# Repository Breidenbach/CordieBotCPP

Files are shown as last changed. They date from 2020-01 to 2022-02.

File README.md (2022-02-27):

# Cordiebot2
This bot was created from a brass lamp found in a resale store. CordieBot 2 is a remake of the original Arduino version which was made as a present for my granddaughter's 11th birthday.

Here is a video of the CordieBot in action...  

https://user-images.githubusercontent.com/1779744/133836883-783d6fb2-bbbe-4077-a870-86ad14fcd4a6.mp4

The original Arduino version can be found in the repository: https://github.com/Breidenbach/CordieBot .

Note that the CordieBot is a bot named after my granddaughter Cordie (duh).

The new and improved CordieBot uses a Raspberry Pi model 3 A+ with logic written in C++.

- Another version is here on github in Python, but had many mysterious memory leaks and could only run a few hours before it used up all system memory resources.  Clearly that was unacceptable, so this version was created in the hopes that I could control memory leaks better in C++ than in Python.

This version uses logic similar to the original for the light show, but now has new features:
- Uses the Cepstral voice for better speach.
- Senses the number of times the touch switch is pressed in a short time:
  -  1 touch and CordieBot says the time of day and date, possibly followed by a proclamation.
  -  2 touches and she says the current weather based on the location of the CordieBot, possibly followed by a proclamation.
  -  3 touches and she says the quote for the day from BrainyQuote.com.
  -  4 touches to repeat the previous proclamation.
  -  5 touches and she tells her version.
  -  8 touches and she tells her origin story.
  -  9 touches and she tells her internal temperature.
- Holding the button for more than 5 seconds causes a shutdown of the system, so that a reboot can occur.  CordieBot must be powered off and powered back on to reboot.
- Checks for a USB drive on start up, and when internet access is disrupted.  If the USB drive is found, checks for a new wpa_supplicant.conf file or cordiebot executable files.  If either is found, copy the file(s) using special scripts into the appropriate directory. (the executable files are only copied if the date on the files is newer than the dates on the CordieBot) Thus this version has the capability of changing the WIFI name and password without a keyboard as well as updating the software.  The USB drive is unmounted after files are copied, as it is expected that the USB drive will be removed after this process.
- This version uses multithreading to overlap the light show and speech.
- The CordieBot has an internal fan and temperature sensor, so that when the internal temperature is high the fan may help cool its logic.

## PROCLAMATIONS

After the weather and time messages, the CordieBot will randomly make a proclamation drawn from a file of messages.  There are three types of proclamations:  for a specific date, for a specific month and day of any year, and for any date.  Proclamation examples:  "Today is mom's birthday" and "I am not the droid you are looking for".  The random selection is prioritized to most often select the current day's statements, followed by those that are for any year on the current date, followed by any other statements.

The proclamation file can be updated remotely using PubNub as a secure communication channel to the CordieBot and cbot_communication on a host computer.  Messages may be added, updated, deleted, and retrieved.  Using the cordieBot_listen program on a local RaspberryPi, the messages can be checked for how they will sound when they are spoken.  Sometimes phonetic editing is required to make a message sound good.  The message text may be altered using the Speech Synthesis Markup Language (https://www.w3.org/TR/speech-synthesis11/) and then tested using a local RaspberryPi.

## DEPENDENCIES

wiringPi is used to access the Pi hardware inputs and outputs.  aoss is used to speak the phrases.

## FILES

### Library modules:
- cbotLights (.cpp and .h) provides the ramping and color change routines for the tri-color LEDs.
- cbotButton (.cpp and .h) debounces and counts presses of the touch switch.
- GPIOtoWiringpi.h maps RaspberryPi GPIO numbers to Wiring Pi numbers.
- messages (.cpp and .h) handles many functions relating to loading, updating, and storing the proclamation file.
- wiringPiMCP3002 (.cpp and .h) connects to the MCP3002 chip over SPI to read temperature values from the TMP36 sensor.
- wiringPiTLC59711 (.cpp and .h) sends data to the adafruit TLC59711 LED PWM board.

### The CordieBot application:
  - cordiebot: the main script
  - CordieBot update scripts, executed when a USB drive is sensed:
    - cordiebot_ctl.sh: copies cordiebot files from a USB drive to the current directory if the files on the USB are newer, always copiies the wpa_supplicant.conf file to /etc/wpa_supplicant
  - cordiebot_listen:  uses PubNub to communicate with the html app on home computer 
  - cordiebot_speak:  auxiliary program to receive the message from the html file and speak it.  This provides the abiity to listen to the messages prior to updating the proclamation file.  
### Scripts to remotely update the proclamation file:
  - cbot_communication.html:  communicates from a host computer to the CordieBot to maintain the file of proclamations spoken after the time is spoken.
  - Cbot_style.css:  style definitions used by cbot_communication.html
### Support files:
  - createproclamationfile.py:  Used to create an initial list of statements for the CordieBot to recite.
  - keys.js:  container for the CordieBot PubNub keyes used for communication to the CordieBot.  This file is used in all the files used in the PubNub communications - the host computer HTML file and CordieBot's listen program.
  - cordiebot_ctl.service.txt, cordiebot.service.txt, and cordiebot_listen.service.txt: These files, with the .txt extension removed, should be place in the /etc/systemd/system/ directory to start the CordieBot applications when the system is booted.

## DIRECTORY STRUCTURE

Make files and execution defaults are dependent on the file structure below.  Note that after building the application files, the executables must be moved to /home/[user]/CordiBot2 to be used automatically on boot.

/home/[user]/CordieBot2/ (Executables and scripts for running CordieBot)

/home/[user]/CordieBot2logs/  (Directory for logs when auto running at boot.  This directory must have write permissions for all.)

/home/[user]/ccpCordie/ (files for building CordieBot)
  - cbot/ (cordiebot main source files)
  - lib/ (specific libraries created for cordiebot features)
  - c-core/ (PubNub files)

## BOOT STARTUP

To start CordieBot on reboot, move the cordiebot_ctl.service.txt, cordiebot.service.txt, and cordiebot_listen.service.txt files to /etc/systemd/system/ with the .txt extension removed.  Then execute the following commands:

  - sudo systemctl disable cordiebot_ctl
  - sudo systemctl disable cordiebot
  - sudo systemctl disable cordiebot_listen
  - sudo systemctl daemon-reload
  - sudo systemctl enable cordiebot_ctl
  - sudo systemctl enable cordiebot
  - sudo systemctl enable cordiebot_listen

## PRINTED CIRCUIT BOARD

To simplify connecting to external devices and provide some interface logic, a small PCB as been developed in the format similar to the RaspberryPi HAT.  The major diference is that this board does not have the ROM to identify it to the RaspberryPi.  The board was developed using KiCad, and files for the board are included in this repository in the PCB directory.

## HARDWARE

As mentioned above, the computer for the CordieBot is a RaspberryPi model 3A+.  Additional logic includes:
-  TMP36GT9Z temperature sensor
-  MCP3002 analog to digital converter (for reading the temperature sensor)
-  PAM8302A audio amplifier
-  AT42QT1010 adafruit momentary touch sensor
-  TLC59711 adafruit 12 channel 16 bit PWM LED driver
-  Sunon GM0501PFB3-8 fan
-  HEP170 diode and 2N2222 transistor for the fan driver
-  Miscellaneos resistors, capacitors, wiring.

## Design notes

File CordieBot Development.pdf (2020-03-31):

# CordieBot Design and Software

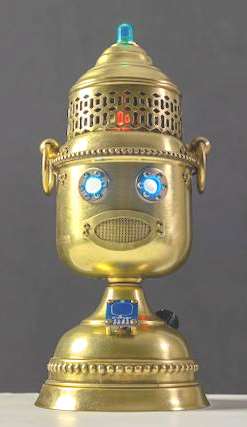
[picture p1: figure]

## A creation by Hal Breidenbach

2020

Photo: Jennifer Patselas

2

### Table of Contents

3

### Background

This project was one of the most complex that I have worked on as an individual. The initial concept was simple, and contained in the first version. Using a repurposed lamp as a body, make a talking head which would tell time, make some inane comments in a somewhat mechanical voice, and display a light show.

The first version, simply named CordieBot, was based on an Arduino computer. It did the light show, had a number of comments to recite, and some time after
my granddaughter Cordie received it she delegated it to back of a
bookshelf.

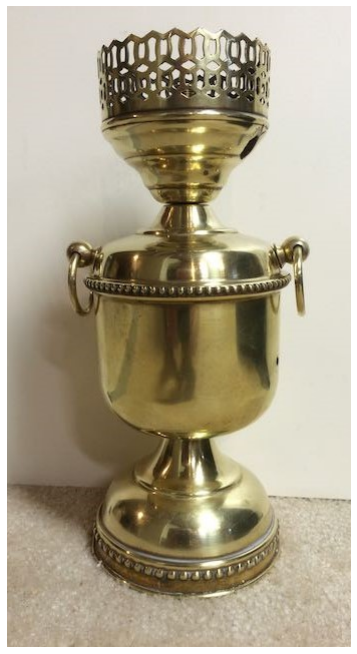
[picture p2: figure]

Clearly, a more interesting bot was needed. But the capacity of the Arduino had been exhausted. Enter the RaspberryPi 3 A+. This computer could fit inside the lamp body, and had plenty of horsepower to do more processing. In addition, it has built in WiFi.

The CordieBot now can give the time of day along with informative or inane comments in a reasonably natural sounding voice, give the temperature and weather outside, recite a quote for the day, and when it gets warm inside its body it can turn on a cooling fan. It has a comparable light show to its predecessor, it can be updated using a USB drive, and the messages it recites can be updated over the web using secure communications.

Additionally, since the messages will be spoken, I wrote a script to run on the RaspberryPi to simply state the message so I can listen
to it before I insert it into the file of messages that are played after
the time is spoken.

The new capabilities were initially all programmed using Python, but when checking memory usage, it was clear that there was a memory leak, and a significant one. The memory on the RaspberryPi was totally filled in less than 24 hours. I was using a number of packages downloaded from free sites, and I could not locate the leak. After some effort at fixing the problem, I decided that the easier path would be to rewrite the code in c++.

Overall, the current CordieBot is 3-1/2 years in the making, although there have been long gaps in the development process. It contains about 3700 lines of original code in addition to the downloaded libraries.

Figure 1 The Lamp

4

### CordieBot components

Hardware—a repurposed lamp, RaspberryPi, lights and sound.
CordieBot software—resident on the CordieBot, written in c++.
CordieBot message management software—resident on the CordieBot, written in c++. CordieBot update scripts—resident on the CordieBot, written in shell script.
Message web page—running on a host computer, written with JavaScript with a CSS file. Message test software—running on a RaspberryPi so messages can be heard before being sent to the CordieBot. Written in c++.

### The learning curve

The CordieBot software challenged me to learn new applications, tools, and techniques:
1. Getting PubNub (the communications software) to work on the RaspberryPi.
2. Writing a web page to communicate with the CordieBot 2.
3. Using json to format and decode the messages.
4. Interfacing an Analog to Digital translation chip to the RaspberryPi and generally using the R-Pi hardware I/O.

### 5. Programming the speech functions and multi threading the software to overlap the light

show and speech.
6. Updating the WiFi access from a USB drive.
7. Updating its own programs from a USB drive.
8. Using a single button to control the program functions.

### Speech

For the natural sounding speech that CordieBot 2 has I purchased the Callie voice from Cepstral (cepstral.com). The speech is actually delivered through a program called Swift, and is accessed using aoss on the R-Pi. I slowed the speech down about 1/3 to make it clearer and easier to understand. It is possible to insert pauses, stress and pitch changes, and phonetic strings into the speech commands. I found the pauses useful, the others not as much.

### Light show

While the speech capability is a major feature of the CordieBot, the light show adds drama. As a talking head, it is important to know when it is awake. When requested to speak, the Cordie-Bot LED eyes are ramped up in a soft blue. Then an LED in the interior (brain) and on the top (head) are ramped through a series of random colors. When the speech is done, the eyes are ramped down to dark. A class is defined to handle the light show and ramping the eyes.

5

### Controlling the CordieBot—the touch button

On the front of the CordieBot is a blue touch sensitive button which selects the function. Based on the selection, the CordieBot speaks a desired response. The selection is based on the number of touches in a short period of time.
1 Speak the time, with a possible message.
2 Announce the local weather and temperature.
3 Read the “Quote of the Day” off the Quote of the Day website. 4 Repeat the last message spoken.
5 Say its version number.
6 Check for updates.

### 8 Recite the origin story of the CordieBot

9 Say its internal temperature.

### 17 Say “You found an Easter egg, good job”. This last command is not publicly

documented, I am curious if it will be found.

The button has its own class to read the button and determine the number of touches. There is an allowable interval separating the touches, and when no touches have been sensed for a longer period of time the number of touches that has been sensed is returned to the calling routine.

### CordieBot Communications

The CordieBot communicates with a server computer to update a message file. The components of the communication capability include and html script running in a browser on the server, a program on the Raspberry Pi, and a communication link.

### Messages

The message feature of the CordieBot was the driver behind much of its other capabilities. The messages are kept in a file (proclamations.txt) on the CordieBot in json format. Three c++ classes, Message, MsgList, and MessageBank, provide the ability to update and access the messages from a resident vector. At start-up the messages are read into the vector, and the messages are re-read whenever the file is updated. The message management software receives updates from the host computer and updates the file as needed. The message management software, accessed from another computer, has the capability to:
Add messages
Change messages
Delete messages
Retrieve a message (back to the web process) Retrieve all messages
Resequence the messages

The messages are formatted to contain the following:

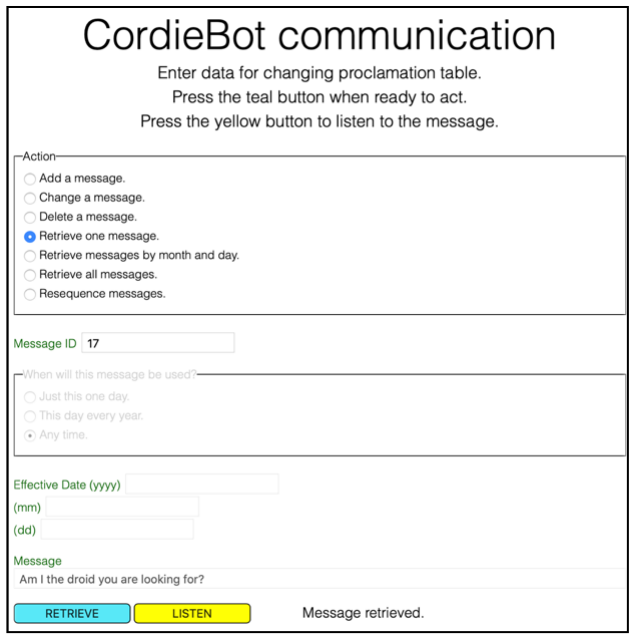
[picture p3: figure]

6

ID – a unique identification number Year, Month, and Day
Type
Content – what will actually be spoken

The message type describes how the message will be used.
Type 1 – the message has a year, month, and day on which it will be used (this can be used to announce a special event that only occurs once).
Type 2 – the message has a month and day and may be used on that day any year (this can be used for announcing a birthday or anniversary).
Type 3 – contains no date values, and may be used any time.

The messages are used randomly, and many times the time will be spoken with no message at all. The software is structured to prefer the type 1 message if one is present for that date, then a type 2 message if one is present for that day of the year, and if neither of the above a type 3 message.

### PubNub

PubNub is a system of software that can be used for a chat application (plus many other uses). For individual non-commercial use it is free. It uses keys that are many characters long so it is very secure. And it has sample
software for web pages and for
C++. The communication from
the host computer is published on a channel (in CordieBot’s case, from an html web page) and received by the CordieBot which subscribes to that channel. Both the channel name and the keys must match. The CordieBot can then publish a response on that channel, and the web page, subscribing to that channel, can receive the response and display it. The PubNub keys are kept in a separate file, keys.js, which can be used by any of the programs that contain PubNub functions: the update program on the CordieBot, the html script on the host computer, and the speak program on another R-Pi.
Figure 2 Screen shot of the message management page.

7

### The host computer web page

On the host computer I wanted an application that would let me do any maintenance on the list of messages located on the CordieBot. This, with PubNub, lets me add, change, delete, and display messages remotely, with a secure connection (the PubNub keys contain 32 unique characters). With this connection, I can add from home new messages for my granddaughter to hear the next time she checks the time. I can have a local R-Pi set up to listen to the messages before they are sent. The web page (figure 2) is written in JavaScript and uses a CSS file that my daughter created.

### “Headless” updates to the CordieBot software

The CordieBot application can be commanded to check for a USB memory stick, and if present will check for a wpa_conf file to add or change a WiFi connection, as well as checking for updated application software. If the software is being update, the application will move the new version to the appropriate directory and then reboot.

### Construction

When I found this brass lamp in the Habitat Restore, I had just a glimmer of what it would become. The rings on the sides do look a bit like earrings, and the body something like a face, so I decided to take that idea wherever it would lead me.

The following description of how the CordieBot was constructed is not intended to be a how-to. It is unlikely that you will find a lamp exactly like the one I found. But perhaps you can get some ideas of what you can do from the way I constructed the CordieBot.

The separate parts of the lamp are held together by two 3/8” hollow threaded rods that are common to most lamps. When the parts are re-ordered, the same rod may be used to hold the new arrangement together. Since it is hollow, the wiring can be run from one segment to the next.

Note that the very top of the lamp is inverted, making a space at the top that is open. Inside this open space is an LED which I refer to as the brain lamp. At the top of the hollow tube that holds the upper part to the main part of the head is another
10mm LED which fits nicely the end of that tube. I refer to
it as the head lamp.

The eyes are attached to a piece of perf board set behind the eyeholes, which are bordered by brass washer held to the face by 6 2-28x1/8” bolts giving a steampunk look to the construction.
The lips are a cutout piece of sheet brass over brass screen
obscuring a hole to the interior. The speaker is behind the
hole, and the lips are held to the face by 4 of the 2-56 x

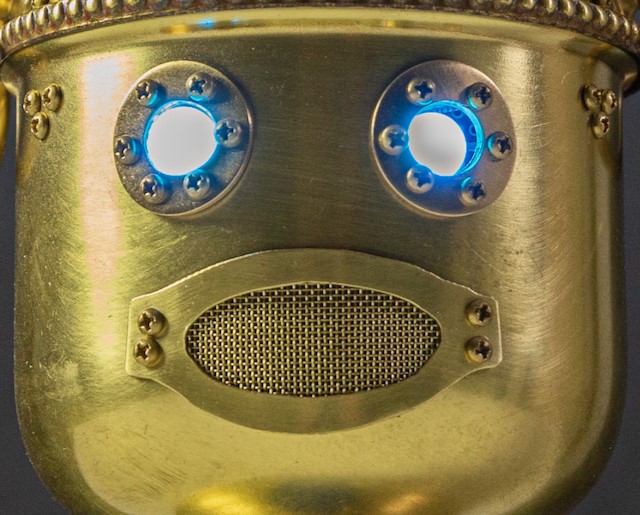
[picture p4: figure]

1/8” bolts. An interior bracket holds the speaker in place, Figure 3 Face detail.

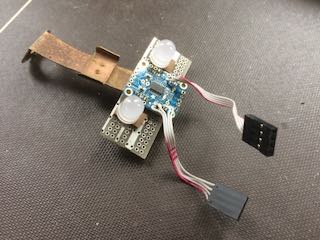
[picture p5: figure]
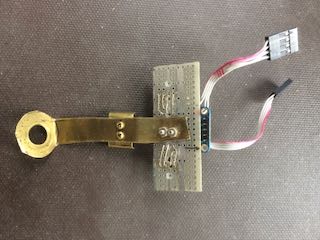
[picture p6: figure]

8

and supports a small piece of perf board which holds the eyes and the LED PWM board.

### Interior Bracket

The interior bracket is the only hardware construction inside the CordieBot. It is sized to fit the space in the lamp. The bottom of the bracket has a 3/8” hole and fits over the rod connecting the base to the head. This allows the bracket to be held by the same nut that keeps the head attached to the base. The bracket has a U shaped holder to keep the speaker from sliding. The bracket is bent so that the eyes are held in place behind the eyeholes, and there is tension on the speaker to hold it in place. A small piece of foam on the back of the speaker helps keep it steady without affecting the sound. (Figures 4 and 5)

The wires from the eye LEDs on the perf board are woven through holes in the board and back up to the LED PWM board. A small piece of 1/8” Masonite spaces pushes the eyes out a bit to let them project through the eyeholes better. The head and brain lamps connect to connectors wired to the LED PWM board. (Figure 6)

Figure 4 Lamp and speaker assembly showing eyes and PWM driver board. The flanges at the midpoint hold the speaker in place.

Figure 5 Rear side of the lamp and speaker assembly. Note that the perf board is connected to the bracket by two 2-56 bolts.

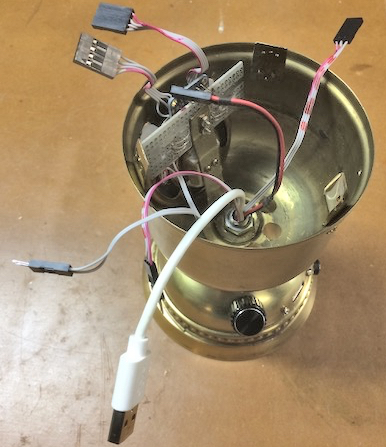
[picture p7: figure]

Figure 6 Interior of the “head” showing the installed eye bracket and wires from the base.

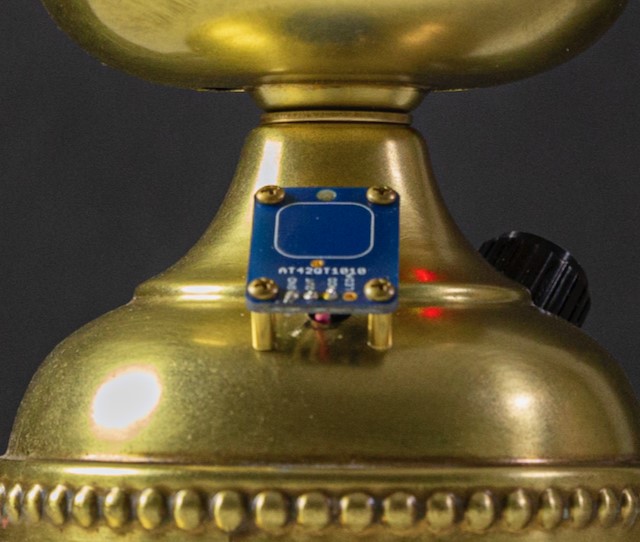
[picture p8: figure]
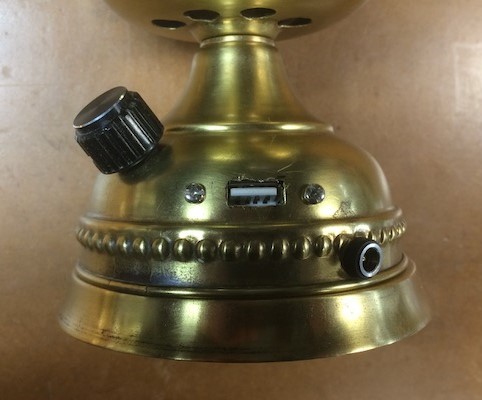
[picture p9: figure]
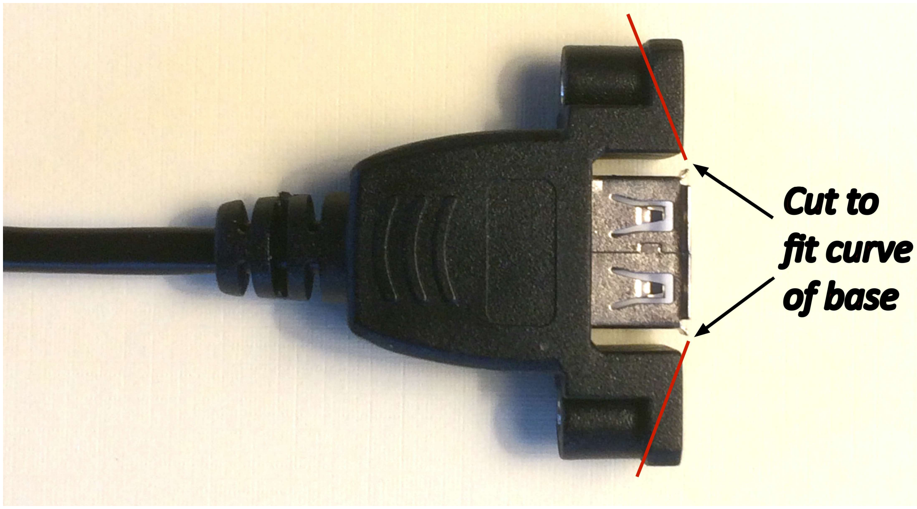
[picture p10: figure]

9

### The Base

The base of the CordieBot holds the input button, the volume control, power input, and a USB connector that directly connects to the R-Pi.

The volume, power, and USB are on the back, while the input button is on the front. The button is held in place by four 2-56 x 1/2” bolts and is held away from the base by 1/4” pieces of 1/6” brass tubing.

To make the USB cable fit into the circular form of the base, I cut the corners off of the cable. (Figure 10)

The wires will be fed up through the 3/8” threaded tube that holds the base to the head. After the wires are fed

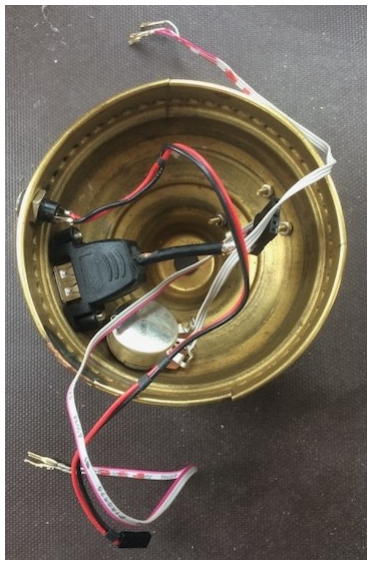
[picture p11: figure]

through the tube they may be inserted into their connectors.

Figure 7 Rear of the base, showing the volume control, USB port, and power connector.

Figure 8 Front of the base, showing the touch button.

Figure 9 Inside the base.

Figure 10 Cuts to end of USB cable.

10

### The Upper Head

Two parts from the original lamp make up the upper head. The very top part is inverted from the original lamp. With its open cutout design it seemed just the place to put a brain light. The two pieces are held together with a length of the standard 3/8” threaded rod. The very top light, or head light, is glued to the end of the threaded rod. The wires for this light are soldered to the LED leads and insulated with pieces of heat shrink tubing. The head lamp and brain lamp are programmed to do a light show any the CordieBot speaks.

In addition, there is a miniature fan which is operated when the temperature gets too high in the CordieBot to cool the interior. The fan moves air from the interior through a hole in the bottom of the two pieces and is hidden by the grated portion of the top of the two. It is held in place by four 2-56 x 1/2” bolts. The brain lamp is glued into a 3/8” hole which is also inside the perimeter of the grated portion of the top. Figure 12 shows the locations of these components, as well as the wires going to the head lamp through the hollow

threaded rod. Note that there are ventilation holes in the body of the head, which can be seen in figure 7.

Since the Raspberry Pi will be inside the head, the typical threaded rod structure of a lamp cannot be used to hold the parts together. Figure 13 shows the location of the bracket, which is held by six 2-56 x 1/8” screws. The bracket holes for the screws are tapped so no nuts are required. Six screws are hardly necessary, but adds to the steam punky look of the CordieBot. There are three brackets, one at each side just in front of the loops, and
one in the middle in the back. The brackets may also be
seen in Figure 12 (the back side is at the top left of the picture).

Figure 11 Upper head detail

Figure 12 Interior of the top pieces.

Figure 13 Bracket to hold the top on.

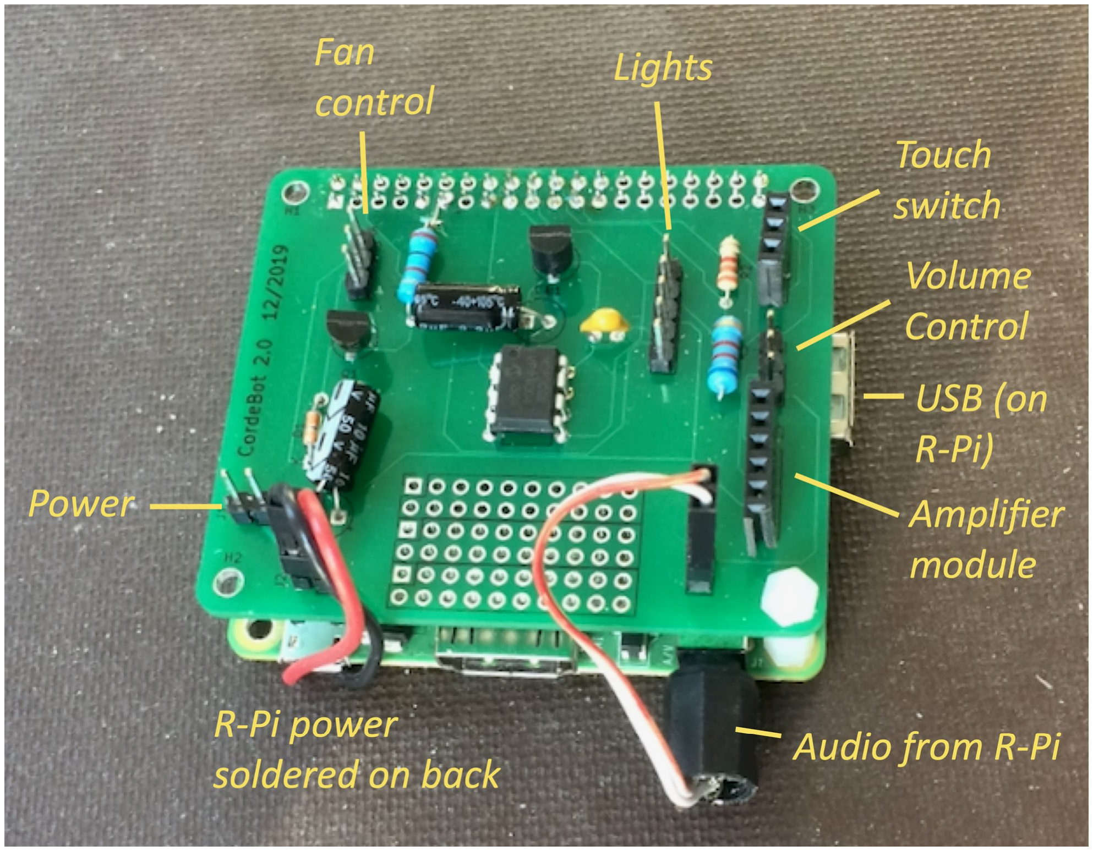
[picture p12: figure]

11

### Electronics and the Raspberry Pi

The electronics interfacing the Raspberry Pi with the daughter boards and other components are on a custom PC board. It is similar to the Raspberry Pi HAT, but lacks the ROM to tell the R-Pi what the board is. Since this is a unique and dedicated application, I didn’t feel it was necessary to have the ROM ID. I also didn’t feel a need to go through the learning curve of including it in the design and altering the software to look for the ID. The populated interface board is shown in Figure 14.

Note that the power to the whole system attaches to this board, and that a connector from this board supplies power to the R-Pi. While there are 5 volt power lines on the 40 pin connector, these are not protected and it is better to supply power to the R-Pi as if it were connected to the power input jack.

A complete set of schematics and a design of the PCB board is available in another document.

The Raspberry Pi is simply inserted into the head of the CordieBot. I originally planned to connect it with bolts to the back of the head, bur realized that it wasn’t necessary. I did cover anything conductive on the edges of the Raspberry Pi with electrical tape to insure nothing could get shorted out if it did get close to the brass case.

All of my wiring is color coded with the wire for pin 1 marked in red.

Figure 14 Raspberry Pi 3A+ and “HAT”

Figure 15 Raspberry Pi
inside the head.

Figure 16 Under construction. Yes, the rats nest of wiring did get confusing
from time to time, but it
all worked out in the end.

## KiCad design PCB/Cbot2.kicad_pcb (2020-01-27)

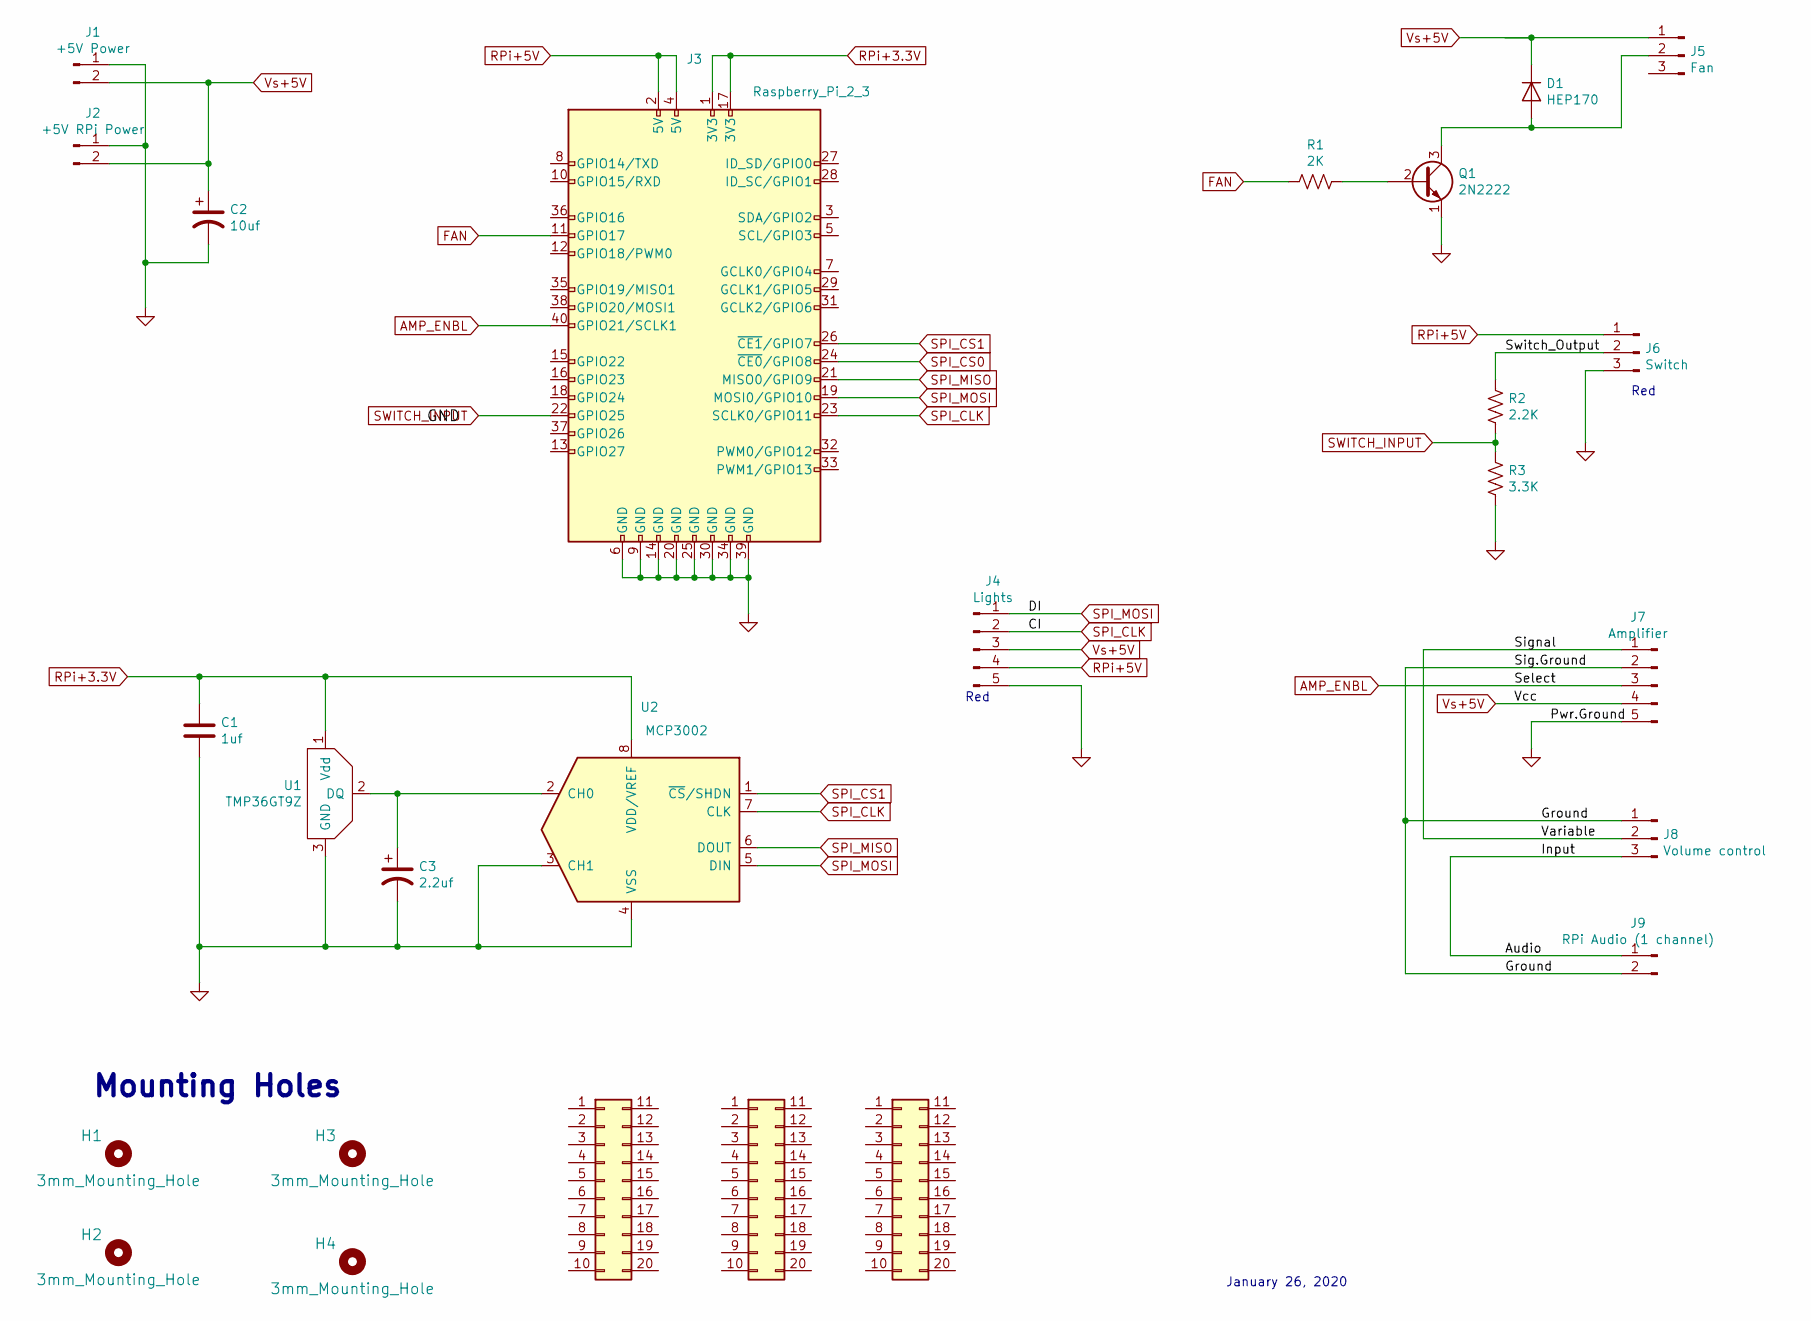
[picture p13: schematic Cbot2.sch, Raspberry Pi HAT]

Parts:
C1: 1uf; C_Disc_D3.0mm_W1.6mm_P2.50mm
C2: 10uf; CP_Radial_Tantal_D5.0mm_P2.50mm
C3: 2.2uf; CP_Radial_Tantal_D5.5mm_P2.50mm
D1: HEP170; D_DO-35_SOD27_P7.62mm_Horizontal
H1, H2, H3, H4: 3mm_Mounting_Hole; NPTH_3mm_ID
J1: +5V Power; PinSocket_1x02_P2.54mm_Vertical
J2: +5V RPi Power; PinSocket_1x02_P2.54mm_Vertical
J3: Raspberry_Pi_2_3; PinSocket_2x20_P2.54mm_Vertical
J4: Lights; PinSocket_1x05_P2.54mm_Vertical
J5: Fan; PinSocket_1x03_P2.54mm_Vertical
J6: Switch; PinSocket_1x03_P2.54mm_Vertical
J7: Amplifier; PinSocket_1x05_P2.54mm_Vertical
J8: Volume control; PinSocket_1x03_P2.54mm_Vertical
J9: RPi Audio (1 channel); PinSocket_1x02_P2.54mm_Vertical
J10, J11, J12: Pads; PinSocket_2x10_P2.54mm_Vertical
Q1: 2N2222; TO-92_HandSolder
R1: 2K; R_Axial_DIN0204_L3.6mm_D1.6mm_P7.62mm_Horizontal
R2: 2.2K; R_Axial_DIN0204_L3.6mm_D1.6mm_P7.62mm_Horizontal
R3: 3.3K; R_Axial_DIN0204_L3.6mm_D1.6mm_P7.62mm_Horizontal
U1: TMP36GT9Z; TO-92L_HandSolder
U2: MCP3002; DIP-8_W7.62mm

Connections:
/Audio: J8.3, J9.1
/Ground: J7.2, J8.1, J9.2
/Signal: J7.1, J8.2
/Switch_Output: J6.2, R2.1
AMP_ENBL: J3.40 (GPIO21/SCLK1), J7.3
FAN: J3.11 (GPIO17), R1.2
GND: C1.2, C2.2, C3.2, J1.1, J2.1, J3.6 (GND), J3.9 (GND), J3.14 (GND), J3.20 (GND), J3.25 (GND), J3.30 (GND), J3.34 (GND), J3.39 (GND), J4.5, J6.3, J7.5, Q1.1 (E), R3.2, U1.3 (GND), U2.3 (CH1), U2.4 (VSS)
unnamed: C3.1, U1.2 (DQ), U2.2 (CH0)
unnamed: D1.2 (A), J5.2, Q1.3 (C)
unnamed: Q1.2 (B), R1.1
RPi+3.3V: C1.1, J3.1 (3V3), J3.17 (3V3), U1.1 (Vdd), U2.8 (VDD/VREF)
RPi+5V: J3.2 (5V), J3.4 (5V), J4.4, J6.1
SPI_CLK: J3.23 (SCLK0/GPIO11), J4.2, U2.7 (CLK)
SPI_CS0: J3.24 (~CE0~/GPIO8)
SPI_CS1: J3.26 (~CE1~/GPIO7), U2.1 (~CS~/SHDN)
SPI_MISO: J3.21 (MISO0/GPIO9), U2.6 (DOUT)
SPI_MOSI: J3.19 (MOSI0/GPIO10), J4.1, U2.5 (DIN)
SWITCH_INPUT: J3.22 (GPIO25), R2.2, R3.1
Vs+5V: C2.1, D1.1 (K), J1.2, J2.2, J4.3, J5.1, J7.4

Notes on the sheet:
Red
Mounting Holes
January 26, 2020

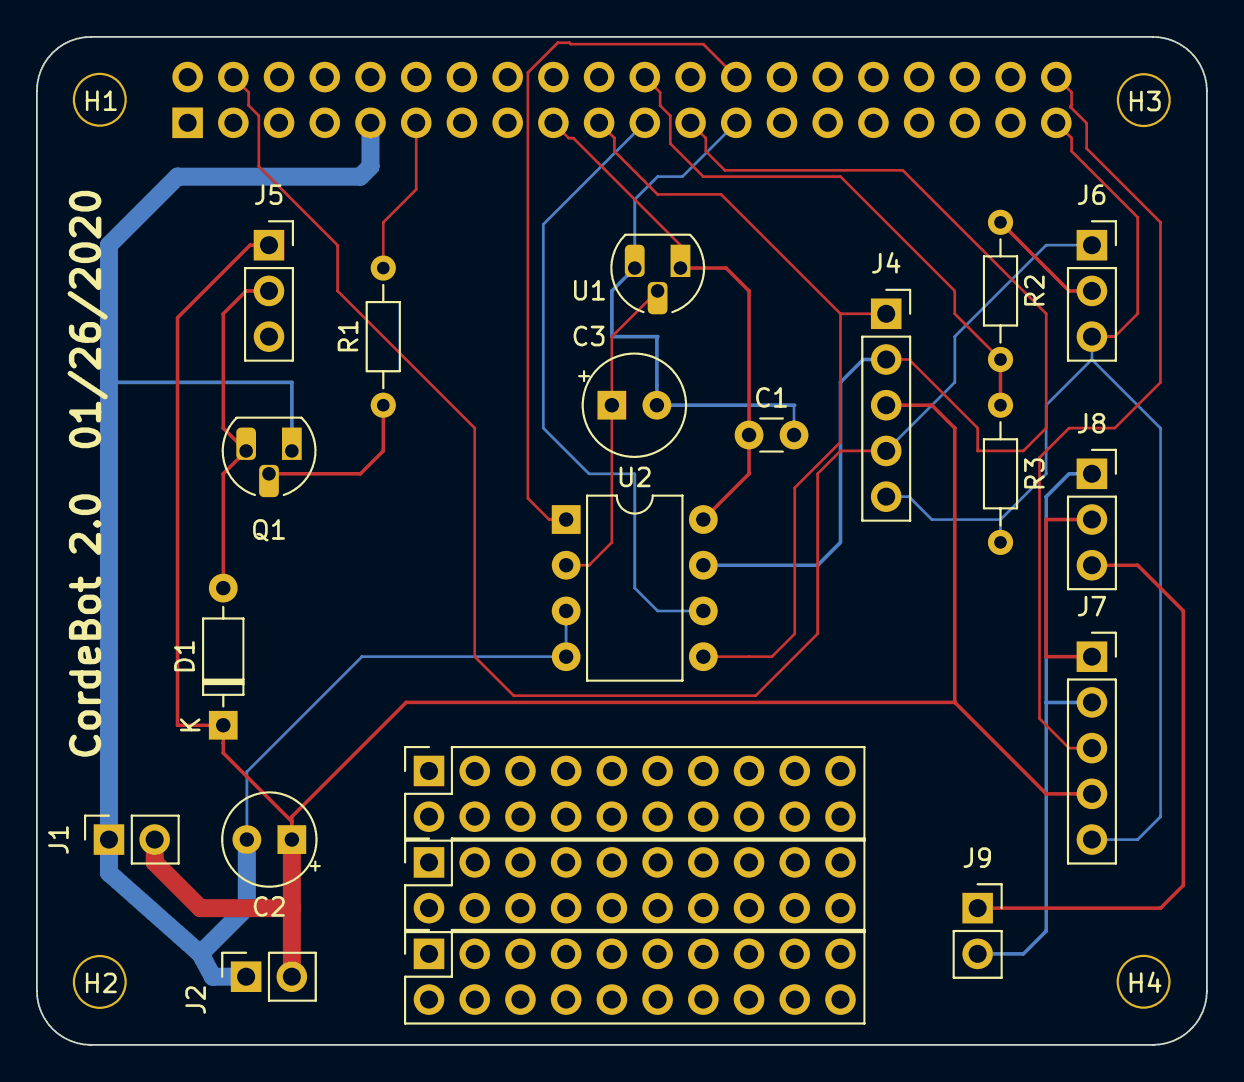
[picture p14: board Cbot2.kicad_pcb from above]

Board: 4 copper layers, 65.0 x 56.0 mm, 26 parts (1 on the bottom side), 18 nets.

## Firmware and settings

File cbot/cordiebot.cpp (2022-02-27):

/* -*- c-file-style:"stroustrup"; indent-tabs-mode: nil -*- */

/**
 *
 *   c++ version of CordieBot
 *
 *   November, 2019 -- Hal Breidenbach
 *   
 **/
 
#include <jsoncpp/json/json.h>
#include <memory>
#include <string>
#include <algorithm>
#include "messages.h"
#include <iostream>
#include <fstream>
#include "countButton.h"
#include "GPIOtoWiringPi.h"
#include <wiringPi.h>
#include "wiringPiTLC59711.h"
#include "wiringPiMCP3002.h"
#include "cbotLights.h"
#include <thread>
#include <random>
#include <curl/curl.h>
#include <bits/stdc++.h> 
#include <curl/curl.h>
#include <unistd.h>
#include <sys/sendfile.h>  // sendfile
#include <fcntl.h>         // open
#include <unistd.h>        // close
#include <sys/stat.h>      // fstat
#include <sys/types.h>     // fstat

//#define DEBUG

//  digital I/O constants
#define AMP_ENABLE GPIO21 
#define HIGH 1
#define LOW 0
#define FAN GPIO17 
#define SWITCH GPIO25 

//  light constants
#define LEFT_EYE 1
#define RIGHT_EYE 2
// eye blink with incr 100 & delay 20 lasts about 2 seconds.
#define BLINK_INCR 100
#define BLINK_DELAY 20
#define HEAD_LAMP 0
#define BRAIN_LAMP 3
// light ramp with ramp 128 & delay 18 lasts just under 3 seconds.
#define RAMP 128
#define LIGHT_DELAY 18
#define MAX_COLOR 65535

// temperature constants
#define TEMPERATURE_CHIP_SELECT 1
#define MCP3002_CHANNEL 0
#define FAN_LIMIT 100.0

//  mbank, lgen, and tempSensor are used many places
MessageBank mbank("proclamations.txt");
std::default_random_engine lgen;
wiringPiMCP3002 tempSensor(TEMPERATURE_CHIP_SELECT, MCP3002_CHANNEL);

/**
 *
 *  convert character array to string.
 *
 *  Thanks to Ivailo Tanusheff
 *
 **/
std::string sconvert(const char *pCh, int arraySize){
    std::string str;
    if (pCh[arraySize-1] == '\0') str.append(pCh);
    else for(int i=0; i<arraySize; i++) str.append(1,pCh[i]);
    return str;
}

/**
 *
 *   replace a portion of a string with another string
 *
 *   Thanks to Mateen Ulhaq
 *
 **/
 
std::string replaceFirst(
    std::string& s,
    const std::string& toReplace,
    const std::string& replaceWith)
{
    std::size_t pos = s.find(toReplace);
    if (pos == std::string::npos) return s;
    return s.replace(pos, toReplace.length(), replaceWith);
}

/** 
 *   convert string to hex for debugging
 **/
#ifdef DEBUG
    inline unsigned int to_uint(char ch)
    {
        // EDIT: multi-cast fix as per David Hammen's comment
        return static_cast<unsigned>(static_cast<unsigned char>(ch));
    }
#endif

/**
 *  format a string with the speech prelude and postlude and pass it to the system
 *  to be spoken.
 *
 **/
void speak(std::string say){
    digitalWrite(AMP_ENABLE, HIGH);  //  AMP_ENABLE was put in to resolve noise between
                                     //  speech events.  Might have been a Python issue.
    const std::string prelude ("nice -n -15 aoss swift \"<prosody rate='-0.3'> ");
    const std::string postlude ("\"");
    std::string totality = prelude;
    totality.append(say);
    totality.append(postlude);
    #ifdef DEBUG
        std::cout << totality << std::endl;
        std::cout << "length of string to speak:  " << totality.length() << std::endl;
        std::cout << std::hex;
        for (char ch : totality)
        {
            std::cout << "0x" << to_uint(ch) << ' '; 
        }
        std::cout << "] end of totality" << std::endl;        
    #endif
    const char *speech = totality.c_str();
    #ifdef DEBUG
        std::cout << "speak: [" << totality.c_str() << "] " << std::endl;
    #endif
    system(speech);
    digitalWrite(AMP_ENABLE, LOW);
}

/**
 *
 *  lightShow(iterations)
 *
 *  Note that the head and brain lamps take iterations + 1 time since they are reset
 *  to zero after the for statement.
 *
 *  setRandLight(r, g, b)
 *
 *  Set the color to random RGB values - randomly selecting one color, setting another 
 *  color to the max value minus the first color, and setting the third to zero.
 *
 **/
 
void setRandLight(int &r, int &g, int &b){
    int v[3] = {0, 0, 0};
    int c1, c2;
    std::uniform_int_distribution<int> ldist(0,MAX_COLOR);
    std::uniform_int_distribution<int> lchoice1(0,2);
    std::uniform_int_distribution<int> lchoice2(0,1);
    c1 = lchoice1(lgen);
    c2 = (c1 + lchoice2(lgen)) % 3;
    v[c1] = ldist(lgen);
    v[c2] = MAX_COLOR - v[c1];
    r = v[0];
    g = v[1];
    b = v[2];
}

void lightShow(int iterations){
    std::uniform_int_distribution<int> ldist(0,MAX_COLOR);
    int HeadR, HeadG, HeadB, BrainR, BrainG, BrainB;
    cbotLights lights = cbotLights();
    lights.setIncrements(LEFT_EYE, BLINK_INCR, BLINK_DELAY);  
    lights.setIncrements(RIGHT_EYE, BLINK_INCR, BLINK_DELAY);
    lights.setIncrements(HEAD_LAMP, RAMP, LIGHT_DELAY);
    lights.setIncrements(BRAIN_LAMP, RAMP, LIGHT_DELAY);
    lights.rampPair(LEFT_EYE, RIGHT_EYE, 0, MAX_COLOR / 2, MAX_COLOR,
                                         0, MAX_COLOR / 2, MAX_COLOR);
    for (int ndx = 0; ndx < iterations; ++ndx){
        setRandLight(HeadR, HeadG, HeadB);
        setRandLight(BrainR, BrainG, BrainB);
        lights.rampPair(HEAD_LAMP, BRAIN_LAMP, HeadR, HeadG, HeadB,
                                            BrainR, BrainG, BrainB);
    }
    lights.rampPair(HEAD_LAMP, BRAIN_LAMP, 0, 0, 0, 0, 0, 0);
    lights.rampPair(LEFT_EYE, RIGHT_EYE, 0, 0, 0, 0, 0, 0);

}

/**
 *
 *   internet tests if the internet can be accessed.
 *
 **/
bool internet(int startcount){
    int test_result = 0;
    while (startcount > 0){
        test_result = system("ping -c 1 8.8.8.8");
        #ifdef DEBUG
            std::cout << "ping return: " << test_result << " cnt: "
                                                 << startcount << std::endl;
        #endif
        if (test_result == 0) { return true;}
        startcount--;
        usleep(1000*1000);  // delay 1 second
    }
    speak("I don't appear to be connected to a why fi network.");
    speak("Check if your why fi is running. Check if anyone changed the "
                "password.  Otherwise, grampa might be able to help.");
    return 0;
}

/**
 *  getDay -- used to get the current day (in several places)
 *
 **/
 
int getDay()
{
    time_t t = time(NULL);
    tm* timePtr = localtime(&t);
    return timePtr->tm_mday;
}

/**
 *
 *   WriteCallback is used when retrieving URLs from the web.
 *
 **/
static size_t WriteCallback(void *contents, size_t size, size_t nmemb, void *userp)
{
    ((std::string*)userp)->append((char*)contents, size * nmemb);
return size * nmemb;
}

/**
 *
 *   checkFan gets the current inside temperature, updates a running average, and
 *   if the temperature is high, turns on the fan.
 *
 **/
void checkFan(float &average_temp){
    float volts = tempSensor.getVolts();
    float sample_temp = (volts * 190.8) - 68.8;
    average_temp = average_temp * 0.95 + sample_temp * 0.05;
    if (average_temp > FAN_LIMIT){
        digitalWrite(FAN, HIGH);  // Turn on fan
    }
    else
    {
        digitalWrite(FAN, LOW);
    }
}

/**
 *
 *  Copy file routine
 *
 **/
 
void copyFile(const char* infile, const char* outfile){
    int source = open(infile, O_RDONLY, 0);
    int dest = open(outfile, O_WRONLY | O_CREAT, 0644);

    // struct required, rationale: function stat() exists also
    struct stat stat_source;
    fstat(source, &stat_source);

    sendfile(dest, source, 0, stat_source.st_size);

    close(source);
    close(dest);
}

/**
 * check for wpa_supplicant.conf file repacement
 *   If file is present, it is moved to /etc/wpa_supplicant/ and can be used
 *   to find a new wifi network or change the password of an existing network.
 *   Note that the system must be restarted to use the new wpa_supplicant.conf 
 *   file.
 *
 **/

void checkForConf() {

    FILE * stream;
    const int max_buffer = 256;
    char buffer[max_buffer];
    bool shutdown = false;
    bool copy_bot = false;
    stream = popen("ls /media/pi/CORDIEBOT 2>&1", "r");
    if (stream)
    {
        while (!feof(stream))
        {
            if (fgets(buffer, max_buffer, stream) != NULL)
            {
                std::cout << "Checking for wpa_supplicant.conf" << std::endl;
                std::size_t found;
                std::string data;
                std::string match_string = "wpa_supplicant.conf\n";
                data.append(buffer);
                std::cout << "cbot line  " << data << std::endl;
        
                found = data.find(match_string);
                if (found!=std::string::npos)
                {
                    std::cout << "got wpa_supplicant.conf: " << std::endl;
                    speak("I have found a new why fi name and password file.  "
                                "I will start using that file after I reboot.");
                    system("sudo /home/pi/CordieBot2/cp_wpa_conf.sh"
                                                        " /media/pi/CORDIEBOT");
                    shutdown = true;
                }
                found = data.find("cp_wpa_conf.sh");
                if (found!=std::string::npos)
                {
                    std::cout << "cp_wpa_conf.sh found" << std::endl;

                    copyFile("/media/pi/CORDIEBOT/cp_wpa_conf.sh","cp_wpa_conf.sh");
                                    
                    system("chmod a+x /home/pi/CordieBot2/cp_wpa_conf.sh");
                    shutdown = true;
                }
                found = data.find("cp_cordiebot.sh");
                if (found!=std::string::npos)
                {
                    std::cout << "cp_cordiebot.sh found" << std::endl;

                    copyFile("/media/pi/CORDIEBOT/cp_cordiebot.sh","cp_cordiebot.sh");
                                    
                    system("chmod a+x /home/pi/CordieBot2/cp_cordiebot.sh");
                    shutdown = true;
                    copy_bot = true;
                } else {
                    found = data.find("cordiebot");
                    if (found!=std::string::npos)
                    {
                        std::cout << "at least one cordiebot"
                                                    " executable found" << std::endl;
                        shutdown = true;
                        copy_bot = true;
                    }
                }
            }
        }
        pclose(stream);
        if (copy_bot)
        {
            speak("I have found a new cordee bot file. "
                            "I will start using that file after I reboot.");
            system("/home/pi/CordieBot2/cp_cordiebot.sh /media/pi/CORDIEBOT");
            system ("chmod a+x cp_cordiebot.sh");
        }
        if (shutdown) 
        {
            speak("Remove the USB stick now.");
            usleep(5000*1000);
            sync();
            #ifdef DEBUG
                std::cout << "reboot starts here " << std::endl;
            #endif        
            system("sudo shutdown -r now");
        }
    }
    if ( ! copy_bot && ! shutdown)
    {
        speak("You asked me to check for updates, but either there are no updates"
                                        " or there is no memory stick present. ");
    }
}

/****************************************************************************
 *
 *   Speech routines
 *
 *   returns a message based on the following rules:
 *   1st - if there are messages specific for the day (type 1) those messages
 *     will be returned with certainty.  If there are several for a day, the
 *     they will be returned from the highest ID to the lowest.  This will
 *     only happen at the beginning of the day, or on a reboot.
 *   2nd - messages will be returned based on random numbers, choosing from
 *     type 1 (special day), type 2 (specific day each year), and then
 *     type 3 (any day).  Within each group, a messages is chosen using
 *     a 2nd random number.  
 *
 ****************************************************************************/
 
std::string getProcMsg(int &type1count){
//    std::default_random_engine lgen;
    #ifdef DEBUG
        std::cout << "type1count: " << type1count << std::endl;
    #endif
    if (type1count > 0) {   //  if there exists a message for today which
                            //  has not been returned.
        int msgnum = type1count;
        type1count--;
        return mbank.getNthEntry(MESSAGE_TYPE_1, msgnum);
    }
    // on to the random groups
    std::uniform_int_distribution<int> typeOneDist(0,4);
    if ((mbank.type1count() > 0) && (typeOneDist(lgen) == 2)){
        if (mbank.type1count() == 1){
            return mbank.getNthEntry(MESSAGE_TYPE_1, 1);
        }
        else
        {
            std::uniform_int_distribution<int> randMsg(1,mbank.type1count());
            return mbank.getNthEntry(MESSAGE_TYPE_1, randMsg(lgen));
        }
    }
    std::uniform_int_distribution<int> typeTwoDist(0,3);
    if ((mbank.type2count() > 0) && (typeTwoDist(lgen) == 1)){
        if (mbank.type2count() == 1){
            return mbank.getNthEntry(MESSAGE_TYPE_2, 1);
        }
        else
        {
            std::uniform_int_distribution<int> randMsg(1,mbank.type2count());
            return mbank.getNthEntry(MESSAGE_TYPE_2, randMsg(lgen));
        }
    }
    std::uniform_int_distribution<int> typeThreeDist(0,2);
    int typeThreeChance = typeThreeDist(lgen);
    #ifdef DEBUG
        std::cout << "typeThreeChance: " << typeThreeChance << std::endl;
    #endif
    if ((mbank.type3count() > 0) && (typeThreeChance == 1)){
        if (mbank.type3count() == 1){
            return mbank.getNthEntry(MESSAGE_TYPE_3, 1);
        }
        else
        {
            std::uniform_int_distribution<int> randMsg(1,mbank.type3count());
            int typeThreeChoice = randMsg(lgen);
            return mbank.getNthEntry(MESSAGE_TYPE_3, typeThreeChoice);
        }
    }
    return "";
}

/**
 *
 *  macro definition for getSpeakTime
 *
 *  calculates the number of light show iterations to speak a string based on the
 *  empirical analysis that a single character takes about 0.11 seconds and that
 *  the light show iterations are about 3 seconds long.  Therefore, 36 characters
 *  should take just one light show iteration.  So the division will round up and
 *  and a bit high, we add 12 to the message length.
 *
 **/
#define getSpeakTime(msg)  ((msg.length() + 12)/27)

void tellTime(int &type1count){
    int const timeSpeakBase = 3;  // light show iterations to speak time with no message.
    std::string ttmessage = getProcMsg(type1count);
    #ifdef DEBUG
        std::cout << "time message: " << ttmessage << std::endl;
    #endif
    int lightShowTime = timeSpeakBase + getSpeakTime(ttmessage);
    std::thread first (lightShow, lightShowTime);
    time_t rawtime;
    struct tm * timeinfo;
    char buffer[80];

    time (&rawtime);
    timeinfo = localtime (&rawtime);

    strftime (buffer,80,"It is %I:%M %p, on  %A,  %B %e, twenty %y \0",timeinfo);
    std::string time_str = sconvert(buffer, 80);
    size_t zero_ndx = time_str.find('\0');
    if (zero_ndx!=std::string::npos)
    {
        time_str.erase(zero_ndx);
    }
    #ifdef DEBUG
        std::cout << time_str << std::endl;
        std::cout << "length of time_str:  " << time_str.length() << std::endl;
    #endif
    std::string str = "<break time='1s' />";
    time_str.append(str);
    time_str.append(ttmessage);

    #ifdef DEBUG
        std::cout << time_str << std::endl;
        std::cout << "length of string to speak:  " << time_str.length() << std::endl;
        std::cout << std::hex;
        for (char ch : time_str)
        {
            std::cout << "0x" << to_uint(ch) << ' '; 
        }
        std::cout << "] end of str" << std::endl;        
    #endif

    speak(time_str);
    first.join();
}
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
int main()
{
    std::cout << "Starting CordieBot 01/15/2022 15:40 " << std::endl;
    std::string intro = "I am cordeebot 2.3";
    
    init();
    
    int counter;
    int periodic_counter = 0;
    float internal_temp = 70.0;   // Initialize to reasonable starting point of 70 deg.
    internet(120);
    #ifdef DEBUG
        std::cout << "Internet present = " << internet(1) << std::endl;
    #endif
    speak(" Hi ");
    double touchButtonGap = 0.8;
    countButton button(SWITCH, touchButtonGap);		// Setup the switch
    int type1count = mbank.type1count();
    int current_day = getDay();
    #ifdef DEBUG
        std::cout << "Today is:  " << current_day << std::endl;
    #endif
	    
    while(1) {
        counter = button.read();
        if( counter == 0){
            usleep(200*1000); 	// Delay 100ms
        } else {
            #ifdef DEBUG
                std::cout << "button:  " << counter << std::endl;
            #endif
            switch (counter) {
                case 1: {   tellTime(type1count);
                            break;
                        }
                case 2: {   tellWeather();
                            break;
                        }
                case 3: {   tellDailyQuote();
                            break;
                        }
                case 4: {   repeatLast();
                            break;
                        }
                case 5: {   speak(intro);
                            break;
                        }
                case 6: {   checkForConf();    // look for USB
                            break;
                        }
                case 8: {   tellOrigin();
                            break;
                        }
                case 9: {   tellInternalTemp(internal_temp);
                            break;
                        }
                case 17: {  tellEasterEgg();
                            break;                        
                        }
                case 255:
                        {
                            speak("goodbye");
                            sync();
                            #ifdef DEBUG
                                std::cout << "reboot starts here " << std::endl;
                            #endif        
                            system("sudo shutdown now");
                        }
                default: {
                            #ifdef DEBUG
                                std::cout << "Invalid option selected." << std::endl;
                            #endif
                        }
            }
        }
        checkFan(internal_temp);
        ++periodic_counter;
        if (periodic_counter > 300){  // check once a minute (with 200ms sleep)
            if (mbank.changed())  // if proclamations file has changed, reload it.
            {
                mbank.reload();
                set_mbank_counts();
                #ifdef DEBUG
                    std::cout << "reloading messages" << std::endl;
                #endif
            }
            int new_day = getDay();
            if (current_day != new_day)  // if day has changed, reset type1count
            {
                current_day = new_day;
                type1count = mbank.type1count();
                set_mbank_counts();
                #ifdef DEBUG
                    std::cout << "it is a new day:  " << current_day << std::endl;
                #endif
            }
            periodic_counter = 0;
        }
    }
    return 0;
}

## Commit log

2019-09-12 Add wiringPi connectors
    Add class .h and .c files for connecting to the MCP3002 and the adafruit TLC59711 hardware.
2019-10-17 Move files to lib directory
    Move wiringPi .hpp and .cpp files to lib directory.
2019-11-26 Create wiringPiPinouts.h
    map from GPIO definitions to wiringPi pin numbers.
2019-12-01 Add touch button class
    Counts # of times touching a button
2019-12-07 Add light class
    cbotLights provides LED functionality, including ramping a pair of lights up and down.
2019-12-20 PCB design upload
    All files used by KiCad to create the December version of the PCB board connecting CordieBot to the various devices.
    [Cbot2.kicad_pcb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]
2019-12-23 Add Fan to CordieBot
    Add fan functions to CordieBot
2020-01-10 Reload messages & minor fixes
    Reload messages when the message file has changed plus a couple of minor changes.
    [cordiebot.cpp]
2020-01-26 Update wiringPiTLC59711.cpp
    Correct color LED pins
2020-01-26 Update cordiebot.cpp
    Add includes needed to access the USB stick.
    Change FAN pin from 24 to 17
    Add diagnostic messages for issues concatenating strings
    Change string concatenation is some places to string.append()
    On startup wait for internet before announcing it isn't present.
    Revise checkFan to update a variable instead of returning a new average.
    Add USB file check and processing.
    Check for \0 value in time conversion string (causing missing \" in string to speak)
    Add announcement of cordiebot version
    Handle switch returning 255 to reboot cordiebot.
    [cordiebot.cpp]
2020-01-27 PCB update
    Move signal from Raspberry Pi pin 12 to pin 11.
    [Cbot2.kicad_pcb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]
2020-02-03 Update cordiebot.cpp
    Change restart on long button press to simple shutdown. Rebooting will require a power off & on.
    [cordiebot.cpp]
2020-02-07 PCB Updates
    Annotate connectors and RED markings.
    [Cbot2.sch]
2020-02-18 Update cordiebot.cpp
    Change light show to be a bit slower and intensify colors.
    Eliminate unused variable warning.
    Make "look for USB" a button option instead of start-up.
2020-02-20 Update cordiebot.cpp
    Change color delay and ramp values for head and brain lamps, to get more intense colors.
    Adjust base times and multipliers to reflect new color times and ramps.
    Reformat some lines so they could print inside normal margins.
    Add message when update files is selected (option 6) but no USB stick or files are present.
    Remove warnings about res not being used.
    Remove unused signal handler routine.
2020-03-31 Add Construction article
    Narrative of how the CordieBot is built, formatted for Microsoft Publisher. A pdf file is included for printing/reading.
2021-11-27 Update cbot_communication.html
    Corrections to set button when retrieving all
    Put in semicolons for consistency
2021-11-27 Update cordiebot.cpp
    change geolocation web site name
    change nice on aoss to -8 from -5
    fix comment in tellDailyQuote
    change version to 2.2 and update date
    change touch button gap to 0.8 from 0.6
    [cordiebot.cpp]
2022-02-27 Initialization routine changes
    Update copy functions in cordiebot.cpp
    Reorganize service routines so that cordiebot_ctl.service executes first, allowing cordiebot.service and cordiebot_listen.service to then execute.
    Replace cp_cordiebot.sh and cp_wpa_conf.sh with cordiebot_ctl.sh.
    Change copy routines in cordiebot_ctl.sh to copy executables only if the USB date is new than the CordieBot date.
    Mount the USB memory in cordiebot_ctl.sh.
    [cordiebot.cpp]
